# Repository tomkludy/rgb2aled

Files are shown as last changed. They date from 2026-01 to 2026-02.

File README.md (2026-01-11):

# rgb2aled

## What it does
This project allows you to connect 1 or 2 RGB LEDs to an addressable LED (WS2812) controller, and provides a standard WS2812 passthrough so that you can daisy-chain additional LEDs - or even daisy chain these controllers together. The LEDs must be 5V, common-anode.

Note that in its current form this cannot support 12V RGB LEDs nor common-cathode LEDs, though it shouldn't be super difficult to make variations to the design for those.

This device can be built for around $15 of materials, and the software is provided here free-of-charge.

## Why is it useful
I have been building a virtual pinball machine, following [Way of the Wrench](https://youtube.com/playlist?list=PLrqlHbqP7FINmGgJoszVvWOOyb8shdfUn&si=c6fxJmt26F5moLLm)'s build guide, but I am not using exactly the same parts. I have a [fire button lockdown bar](https://virtuapin.net/index.php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) from [Virtuapin.net](virtuapin.net), and I have 4 [RGB leaf buttons](https://www.clevelandsoftwaredesign.com/pinball-parts/p/rgb-true-leaf-button) from [Cleveland Software Design](clevelandsoftwaredesign.com). I was having trouble trying to connect them to my cabinet and control them with DOF since I don't have a 5V RGB LED controller. I foolishly tried connecting one to a 12V RGB controller and the "magic smoke" was released! (don't do that!) Emil's videos sparked the idea to adapt these LEDs to support the WS2812 addressable-LED standard, that way I can connect them to my Wemos lighting controller.

There are probably other use cases for hooking "regular" LEDs up to addressable-LED light strips. If you have another use case let me know!

## Hardware
To support 1 RGB LED, you'll need:
- 1x [Arduino Nano v3](https://a.co/d/9rjba7l). Any ATMega328P clone should work as long as it is running at 16MHz.
- 3x [resistors](https://a.co/d/9rjba7l) - anything from 1kΩ to 100kΩ should work fine. I used a mix of 10kΩ and 5.1kΩ resistors that I had lying around.
- 3x N-type MOSFETs. I used [IRLZ44Ns](https://a.co/d/9rjba7l).
- [Male and female JST 3-pin connectors](https://a.co/d/ethh2G7) to connect to a standard WS2812 daisy chain.
- 1x [RGB LED connector](https://a.co/d/aOVf79y).
- Something to mount it on. I used a [1/2 size breadboard from ElectroCookie](https://a.co/d/e8n7Chf).

If you want to support 2 RGB LEDs from one board, add to this:
- 3x additional resistors
- 3x additional N-type MOSFETs
- 1x additional RGB LED connector.

Sorry - there's no way to drive more than 2 LEDs from one Arduino Nano, at least not with this design. The Arduino only has 6 PWM output channels and each LED uses 3 of them. To support my 5 total RGB LEDs I just built 3 of these devices and daisy-chained them.

The board hooks up to a standard addressable-LED strip or controller, acts as 1 or 2 additional "pixels" driving 1 or two connected "dumb" LEDs, and then passes through up any remaining data to additional controllers or light strips.

> [!WARNING]
> Although any number of LEDs can be daisy chained from data-out, make sure if you have more than about 15 or so, that you inject power to the strip immediately after this board in the sequence. Each LED can use up to 60mA power at full brightness. A breadboard is usually only rated for 1-2 amps at most. Usually light strips have both an input connector and separate power and ground inputs - hook those directly to your 5V power supply to avoid sending that much current through this controller.

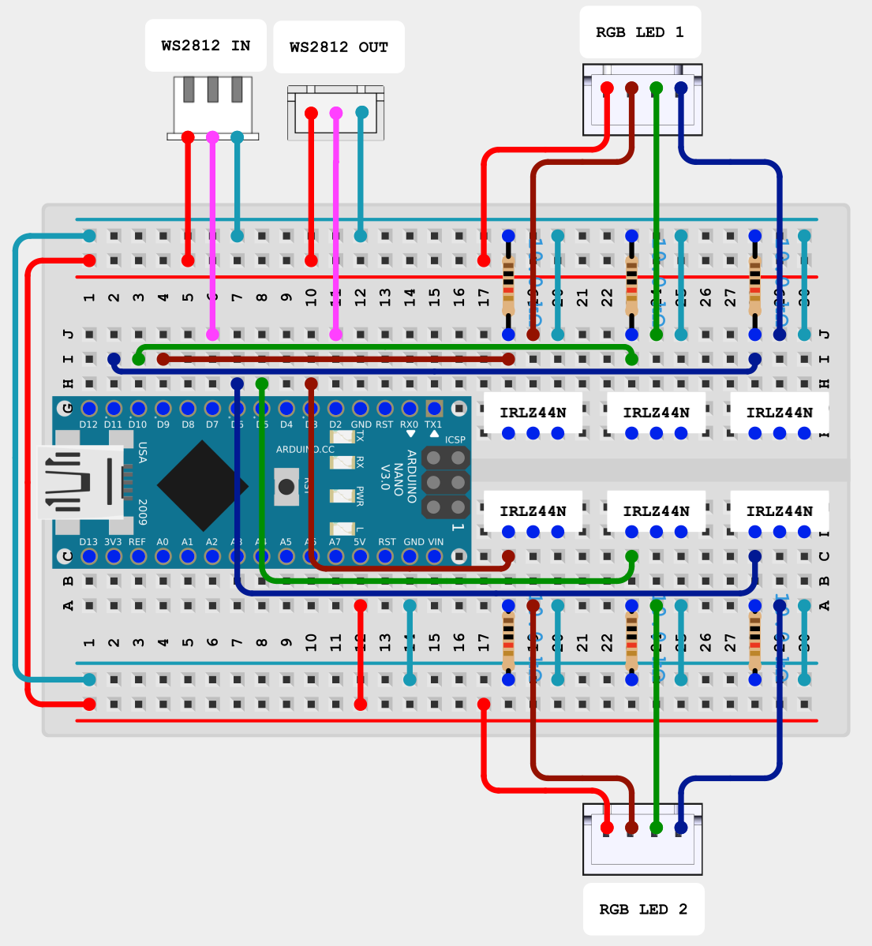
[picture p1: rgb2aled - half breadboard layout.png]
The schemetic diagram is shown [in the PDF](Schematic_RGB-to-ALED.pdf). This circuit will fit on a 1/2 size breadboard, though its a bit tight: 

## Software
Next you need to program the Arduino to make it function. Download and open the free Arduino IDE and create a "sketch". Insert the code from [the .ino file](rgb2aled.ino). If you have only one LED, comment out the line `#define TWO_LEDS`. **This is important!** The board will behave strangely if you don't set or unset `TWO_LEDS` correctly in the code, to match what you actually have connected to the device.

Compile and upload it to your Arduino. Note: I had to select "Tools > Processor > ATMega328P (Old Processor)" for my boards or the code would not upload; YMMV based on the exact hardware you have.

The 16MHz Arduino is just barely fast enough to handle the timing required by using hand-optimized assembly code with fully unrolled loops. As a result the code requires specific clock cycle timing and supports ONLY a 16MHz processor. There are 48MHz and faster Arduinos out there like the Nano r4 and the Nano 33, but those <ins>will not work</ins> with this software.

## Putting it all together
I created 3d-printable cases for these when they are built on the ElectroCookie 1/2-size breadboards; STLs are available in this repo. There are variations for 1 LED or 2 LEDs. Flip the top piece before printing to avoid using support.

To assemble, use M2 x 4mm screws to connect the breadboard to the bottom of the case, route the wires through the correct holes, then use M3 x 6mm screws to connect the top of the case to the bottom of the case. I also suggest a bit of glue gun where the wires pass through the case holes to hold them in place and prevent strain on the soldered wire connections.

## Contributing
If you want to help make this project better, feel free to contribute pull requests!

## FAQ

*Q: Will you sell me a pre-built version?*<br/>
A: No, building electronics is a hobby for me, not my day job. Perhaps someone else would be willing to build it in a more professional package (proper PCB for example) and sell it. You could probably get it made by PCBWay or another circuit manufacturer.

*Q: Can I build it and sell it myself?*<br/>
A: Everything in this repo is licensed under the Creative Commons Attribution License, meaning it is free to use, modify, and redistribute as long as you include attribution to the original author. So, yes! If you do build and sell it, let me know so that I can link to your product.

*Q: Will an Arduino Nano r4 or Nano 33 work?*<br/>
A: I presume the hardware could work if wired the same way, but the software would need to be completely rewritten since the timing is completely different for those boards.

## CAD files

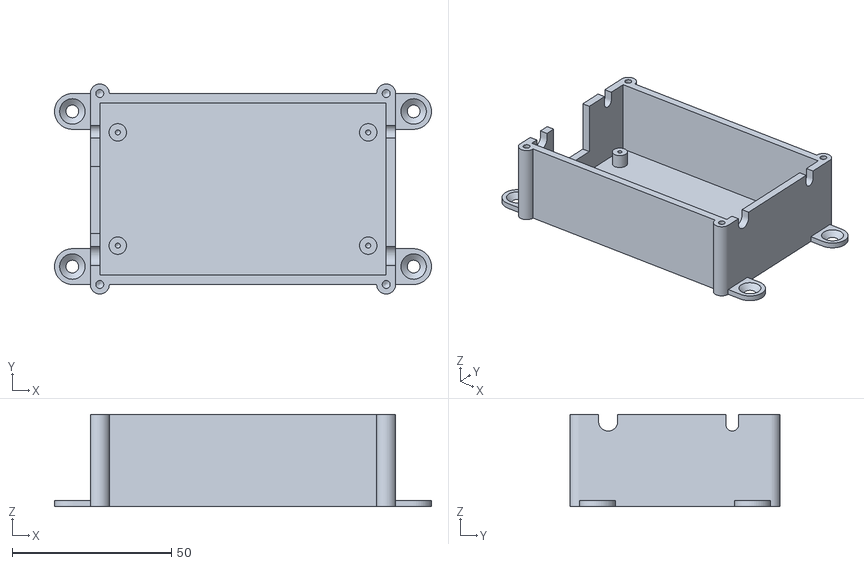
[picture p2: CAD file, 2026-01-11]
RGB to ARGB case - 2 LEDs - bottom.stl
118.5 x 66.0 x 29.0

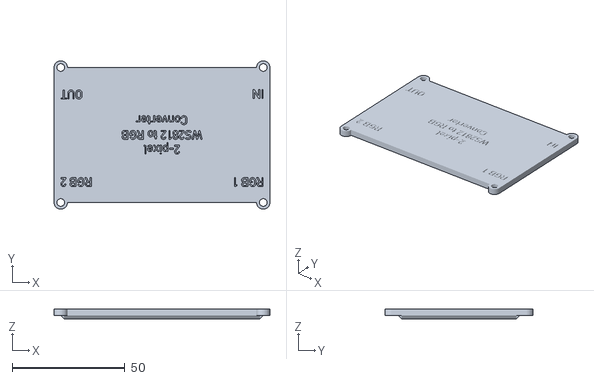
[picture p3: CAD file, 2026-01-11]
RGB to ARGB case - 2 LEDs - top.stl
96.0 x 66.0 x 4.50

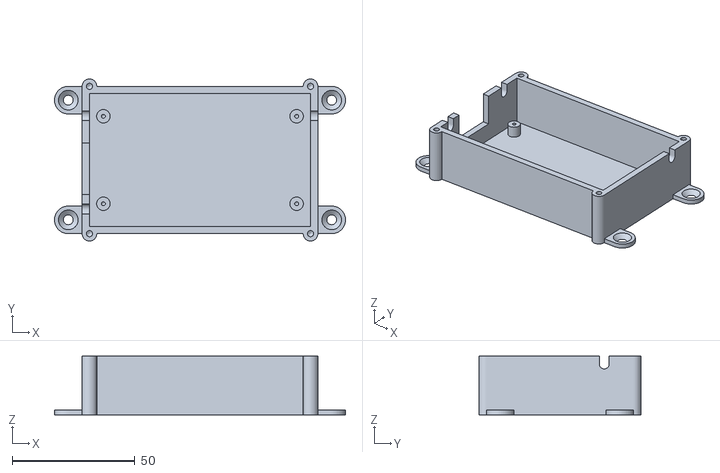
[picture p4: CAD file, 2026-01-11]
RGB to ARGB case - 1 LED - bottom.stl
118.5 x 66.0 x 24.0

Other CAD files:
RGB to ARGB case - 1 LED - top.stl

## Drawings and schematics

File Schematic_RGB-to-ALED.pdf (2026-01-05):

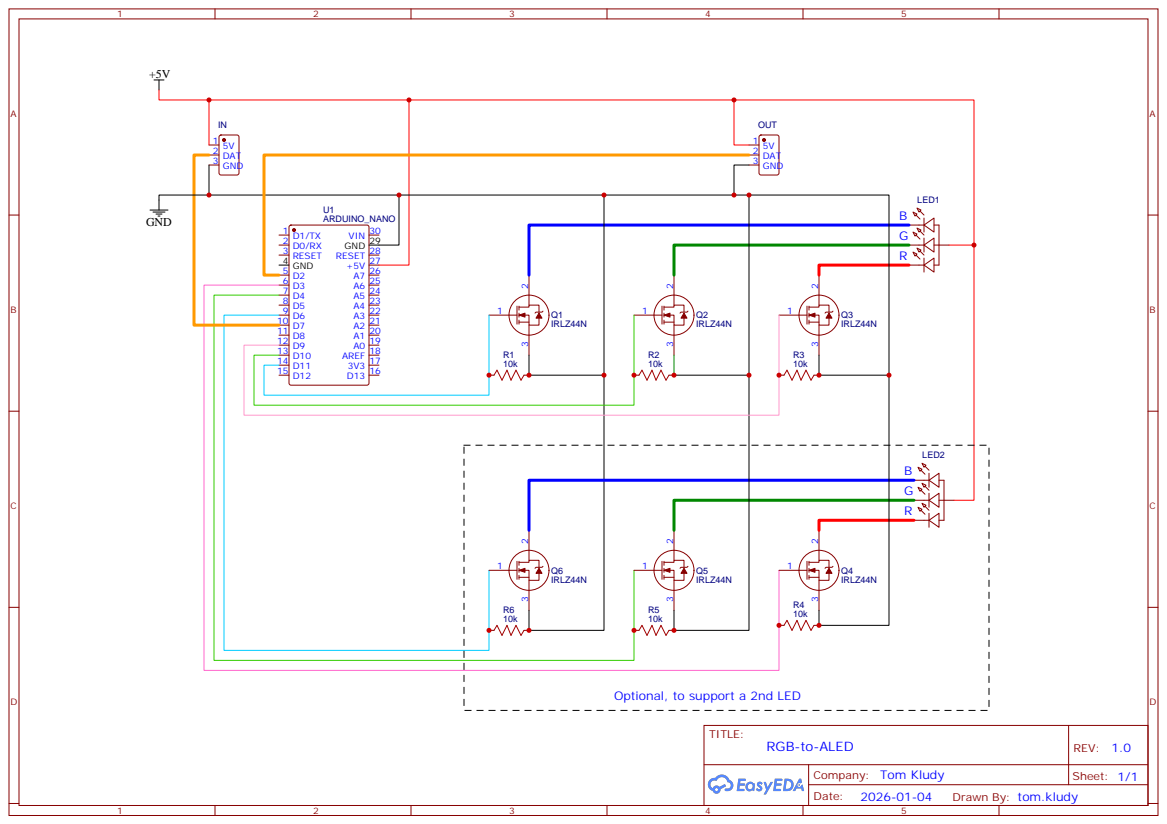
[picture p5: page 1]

Optional, to support a 2nd LED

Drawn By: tom.kludy

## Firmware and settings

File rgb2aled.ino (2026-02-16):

/**
 * WS2812B Hyper-Optimized 1/2 Pixel Controller
 * -------------------------------------------
 * - Target: ATmega328P @ 16MHz (1 cycle = 62.5ns)
 * - Sampling Window: 437.5ns - 562.5ns (Cycles 7-9)
 * - Relay: 1:1 pulse preservation with constant 6-cycle latency.
 * 
 * Captures two pixels (24 bits each, 48 bits total) from WS2812B data stream
 * and outputs the corresponding RGB values to two sets of 3 PWM pins each.
 * Then passes through all subsequent pixels in "burst relay mode".
 *
 * Components:
 * - Arduino Nano (ATmega328P @ 16MHz)
 * - 6x N-Channel Logic Level MOSFETs (e.g., IRLZ44N)
 * - 6x Resistors (10k Ohm) - 1k..100k acceptable
 * - 2x 5V Common-Anode RGB LEDs (LEDs to drive with this controller)
 *
 * Wiring expected:
 * - 5V -> Arduino 5V and LED Anodes
 * - GND -> Arduino GND and MOSFET Sources
 * - WS2812B Data In -> Arduino D7
 * - Arduino D2 -> WS2812B Data Out (daisy chain to rest of strip)
 * - Arduino D9 -> MOSFET 1 Gate -> 10k Resistor -> GND
 * - Arduino D10 -> MOSFET 2 Gate -> 10k Resistor -> GND
 * - Arduino D11 -> MOSFET 3 Gate -> 10k Resistor -> GND
 * - Arduino D3 -> MOSFET 4 Gate -> 10k Resistor -> GND (optional - for 2 LEDs)
 * - Arduino D5 -> MOSFET 5 Gate -> 10k Resistor -> GND (optional - for 2 LEDs)
 * - Arduino D6 -> MOSFET 6 Gate -> 10k Resistor -> GND (optional - for 2 LEDs)
 * - MOSFET 1 Drain: LED 1 RED Cathode
 * - MOSFET 2 Drain: LED 1 GREEN Cathode
 * - MOSFET 3 Drain: LED 1 BLUE Cathode
 * - MOSFET 4 Drain: LED 2 RED Cathode (optional - for 2 LEDs)
 * - MOSFET 5 Drain: LED 2 GREEN Cathode (optional - for 2 LEDs)
 * - MOSFET 6 Drain: LED 2 BLUE Cathode (optional - for 2 LEDs)
 *
 * Estimated max current draw, assuming 2 100mA RGB LEDs at full brightness and
 * no passthrough: 200mA (LEDs) + 30mA (Arduino Nano) = 230mA / 0.23A total, or
 * roughly 1.15W.
 *
 * Note that 5V and GND must be common through the full circuit, but if you are
 * building on a breadboard you should patch additional power into the strip
 * after this device and ensure you are using sufficient gauge wires. ALEDs are
 * typically rated for 60mA at full brightness. So to keep under 1A total, you
 * should not connect more than ~12 additional LEDs to the daisy chain output of
 * this controller without additional power injection.
 * 
 * 
 * rgb2aled  © 2026 by Tom Kludy is licensed under CC BY 4.0. To view a copy of
 * this license, visit https://creativecommons.org/licenses/by/4.0/
 */

#include <avr/io.h>

// Comment the following for 24-bit capture (1 LED).
#define TWO_LEDS

// There is a prototype variant of the board that uses D6 for data in and D7 for data out.
// I do not want to rewire it or maintain two separate codebases, so this define allows
// swapping the input and output pins as needed.
//#define ALTERNATE_DATA_PINS
#ifdef ALTERNATE_DATA_PINS
  #undef TWO_LEDS // ALTERNATE_DATA_PINS only supports 1 LED mode because D6 is used for data in.
  #define DATA_IN    6
  #define DATA_OUT   7
#else
  #define DATA_IN    7
  #define DATA_OUT   2
#endif

void setup() {
  noInterrupts();
  
  // Disable Arduino default timer interrupts
  TIMSK0 = 0; TIMSK1 = 0; TIMSK2 = 0;

  // Pin Direction Setup
  DDRB |= (1 << PB1) | (1 << PB2) | (1 << PB3);   // LED 1 (D9, D10, D11)
  DDRD |= (1 << DDD3) | (1 << DDD5) | (1 << DDD6); // LED 2 (D3, D5, D6)
  
  DDRD &= ~(1 << DATA_IN); // Input (Data In)
  DDRD |= (1 << DATA_OUT); // Output (Relayed Data Out)

  // PWM Timer Setup (Inverting Mode for Common Anode)
  TCCR0A = (1 << COM0A1) | (1 << COM0A0) | (1 << COM0B1) | (1 << COM0B0) | (1 << WGM01) | (1 << WGM00);
  TCCR0B = (1 << CS00);
  TCCR1A = (1 << COM1A1) | (1 << COM1A0) | (1 << COM1B1) | (1 << COM1B0) | (1 << WGM10);
  TCCR1B = (1 << WGM12) | (1 << CS10);
  TCCR2A = (1 << COM2A1) | (1 << COM2A0) | (1 << COM2B1) | (1 << COM2B0) | (1 << WGM21) | (1 << WGM20);
  TCCR2B = (1 << CS20);
  
  // Initialize LEDs to OFF (Common Anode 255 = Off)
  OCR0A = 255; OCR0B = 255; OCR1A = 255; OCR1B = 255; OCR2A = 255; OCR2B = 255;
}

void loop() {
  asm volatile(
    // --- MACROS ---

    // Reads 1 bit: Waits for Rise, Delays to Center, Samples, Waits for Fall
    //
    // Sampling window: 437.5ns - 562.5ns (Cycles 7-9)
    //
    // The Wemos S2 seems to have too short of a high bit pulse width, falling
    // around ~650ns instead of 800ns as expected by WS2812 spec. So we sample
    // earlier than the ideal center. This does run the risk that a LOW bit
    // could be misread as HIGH if the pulse drops late; by the spec, a LOW bit
    // can be as long as 500ns. However the Wemos S2 seems to have a maximum
    // LOW pulse width of around 400ns in practice.
    ".macro READ_BIT reg \n\t"
      // 1. Wait for Rise
      // Best Case (Rise just before sample): 2 cycles latency.
      // Worst Case (Rise just after sample): 4 cycles latency.
      "1: sbis 0x09, %[data_in] \n\t" "rjmp 1b \n\t"
      // [Range: T=2 to T=4] [125ns - 250ns]

      // 2. Delay to Center (4 NOPs + 1 LSL)
      "nop \n\t" "nop \n\t" "nop \n\t" "nop \n\t"
      "lsl \\reg \n\t"        
      // [Range: T=7 to T=9] [437.5ns - 562.5ns] 
      // *** SAMPLING POINT ***
      // WS2812B '0' is HIGH for ~300-400ns. WS2812B '1' is HIGH for ~625-800ns.

      // 3. Sample (2 cycles total)
      // Path 1 (Low): sbic(2) = 2.
      // Path 2 (High): sbic(1) + ori(1) = 2.
      "sbic 0x09, %[data_in] \n\t"     
      "ori \\reg, 1 \n\t"     
      // [Range: T=9 to T=11] [562.5ns - 687.5ns]

      // 4. Wait for Fall (Sync Anchor)
      // Best case (Already Low): sbic(2) = 2 cycles. [Exit T=11-13]
      // Worst case (Wait for edge): sbic(1)+rjmp(2)+sbic(2) = 5 cycles. [Exit T=14-16]
      "2: sbic 0x09, %[data_in] \n\t" "rjmp 2b \n\t"
    ".endm \n\t"

    ".macro READ_BYTE reg \n\t"
      "READ_BIT \\reg \n\t" "READ_BIT \\reg \n\t" "READ_BIT \\reg \n\t" "READ_BIT \\reg \n\t"
      "READ_BIT \\reg \n\t" "READ_BIT \\reg \n\t" "READ_BIT \\reg \n\t" "READ_BIT \\reg \n\t"
    ".endm \n\t"


    // --- 1. INITIAL POWER-ON SYNC ---
    "start_frame_%=: \n\t"
    #ifndef TWO_LEDS
      // since we aren't reading any values for LED 2, we initialize the
      // associated registers to OFF (255 due to inverted signal).
      "ldi r19, 255 \n\t" "ldi r20, 255 \n\t" "ldi r21, 255 \n\t"
    #endif
    "wait_reset_%=: \n\t"
      "ldi r22, 250 \n\t"
    "r_chk_%=: \n\t"
      "sbic 0x09, %[data_in] \n\t" "jmp wait_reset_%= \n\t" 
      "dec r22 \n\t" "brne r_chk_%= \n\t"


    // --- 2. CAPTURE PHASE ---
    "capture_start_%=: \n\t"
    "READ_BYTE r16 \n\t" // G1
    "READ_BYTE r17 \n\t" // R1
    "READ_BYTE r18 \n\t" // B1

    #ifdef TWO_LEDS
      "READ_BYTE r19 \n\t" // G2
      "READ_BYTE r20 \n\t" // R2
      "READ_BYTE r21 \n\t" // B2
    #endif


    // --- 3. RELAY PHASE ---
    "relay_entry_%=: \n\t"
      // Linear timeout: 256 checks * 3 cycles + 4 cycles = 772 cycles (~48us reset window)
      // When LOW: 3 cycles per check (sbis + rjmp)
      // When HIGH occurs at the moment of sbis: 0 cycle delay
      // When HIGH occurs just after sbis: 2 cycles delay (rjmp)
      // Thus, we can be between 0-2 cycles late when detecting HIGH.
      ".rept 256 \n\t"
        "sbis 0x09, %[data_in] \n\t"  // Cycles 1-2: If HIGH, skip next (if LOW, only 1 cycle)
        "rjmp .+6 \n\t"               // Cycles 2-3: If LOW, skip to next iteration

        // The rjmp offset doesn't support labels because we are in a .rept loop.
        // So we need to manually calculate the offset to jump. Each of the
        // instructions is labeled with instruction byte counts for clarity;
        // eg. "[2]" means 2 bytes for instruction(s) on that line. You can
        // then sum those up and make sure the rjmp offset above is correct.

        // We need to keep the bit-start latency to a minimum so we can't spend any
        // extra cycles jumping out of the loop. But we also need to keep the number
        // of instructions in the loop down to avoid "relocation truncated to fit"
        // compilation error.
        "sbi 0x0b, %[data_out] \n\t"  // [2] Cycles 3-4: set HIGH (Pin High at the end of cycle 4)
        "jmp relay_bit_%= \n\t"       // [4] Cycles 5-7: get out of the .rept
      ".endr \n\t"
      "jmp update_now_%= \n\t"        // If we finish 256 reps, it's a RESET. Update LEDs.

    "relay_bit_%=: \n\t"

      // set LOW if 0, clock-synced:  // LOW path  / HIGH path
      "sbis 0x09, %[data_in] \n\t"    // 8         / 8-9   : Sample D7
      "cbi 0x0b, %[data_out] \n\t"    // 9-10      / -     : Set D2 to match D7; 0-bit HIGH duration=6 cycles
      "sbic 0x09, %[data_in] \n\t"    // 11-12     / 10    : Skip next if D7 HIGH
      "rjmp .+0 \n\t"                 // -         / 11-12 : Sync cycle count

      "nop \n\t"                      // Cycle 13

      "cbi 0x0b, %[data_out] \n\t"    // Cycles 14-15: set output LOW (at end of cycle 15); 1-bit HIGH duration=11 cycles
      "jmp relay_entry_%= \n\t"       // Cycles 16-18: Loop back to check for next bit


    // --- 4. UPDATE PHASE ---
    // The only way that we get here is by jumping through 256 relay checks above
    // without seeing any HIGH on the input line. This indicates a reset period.
    //
    // This code executes during the reset gap, when we have a lot of extra time before
    // we expect the next frame to start. (Reset is usually >300ns.) We use this time to do all of the work
    // that we deferred during the capture and relay phases.
    "update_now_%=: \n\t"

    // Invert captured values for Common Anode LEDs
    "com r16 \n\t" "com r17 \n\t" "com r18 \n\t"
    #ifdef TWO_LEDS
      // we only want to invert these if we read them from input;
      // when !TWO_LEDS, we want to leave these untouched so they
      // always contain the OFF value.
      "com r19 \n\t" "com r20 \n\t" "com r21 \n\t"
    #endif

    // Commit to PWM registers
    "sts 0x88, r17 \n\t" // OCR1A (D9)  - LED1 Red
    "sts 0x8A, r16 \n\t" // OCR1B (D10) - LED1 Green
    "sts 0xB3, r18 \n\t" // OCR2A (D11) - LED1 Blue

    "sts 0xB4, r20 \n\t" // OCR2B (D3)  - LED2 Red
    "sts 0x48, r19 \n\t" // OCR0B (D5)  - LED2 Green
    "sts 0x47, r21 \n\t" // OCR0A (D6)  - LED2 Blue

    // Jump directly to capture bits for the next frame.
    "jmp capture_start_%= \n\t" 

    :
    : [data_in] "I" (DATA_IN), [data_out] "I" (DATA_OUT)
    : "r16", "r17", "r18", "r19", "r20", "r21", "r22", "r23", "memory"
  );
}

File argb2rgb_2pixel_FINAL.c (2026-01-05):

/**
 * WS2812B two-pixel ARGB to RGB controller
 *
 * Captures two pixels (24 bits each, 48 bits total) from WS2812B data stream
 * and outputs the corresponding RGB values to two sets of 3 PWM pins each.
 * Then passes through all subsequent pixels in "burst mode", up to 200 pixels
 * total.
 *
 * The timing is carefully tuned for an Arduino Nano (ATmega328P @ 16MHz).
 * It cannot support more than 200 pixels due to timing constraints; even
 * switching the timer counter to 16 bits from 8 bits causes timing issues.
 * This is the primary limiting factor for longer strips.
 *
 * Components:
 * - Arduino Nano (ATmega328P @ 16MHz)
 * - 6x N-Channel Logic Level MOSFETs (e.g., IRLZ44N)
 * - 6x Resistors (10k Ohm) - 1k..100k acceptable
 * - 2x 5V Common-Anode RGB LEDs (LEDs to drive with this controller)
 *
 * Wiring expected:
 * - 5V -> Arduino 5V and LED Anodes
 * - GND -> Arduino GND and MOSFET Sources
 * - WS2812B Data In -> Arduino D7
 * - Arduino D2 -> WS2812B Data Out (daisy chain to rest of strip)
 * - Arduino D9 -> MOSFET 1 Gate -> 10k Resistor -> GND
 * - Arduino D10 -> MOSFET 2 Gate -> 10k Resistor -> GND
 * - Arduino D11 -> MOSFET 3 Gate -> 10k Resistor -> GND
 * - Arduino D3 -> MOSFET 4 Gate -> 10k Resistor -> GND
 * - Arduino D5 -> MOSFET 5 Gate -> 10k Resistor -> GND
 * - Arduino D6 -> MOSFET 6 Gate -> 10k Resistor -> GND
 * - MOSFET 1 Drain: LED 1 RED Cathode
 * - MOSFET 2 Drain: LED 1 GREEN Cathode
 * - MOSFET 3 Drain: LED 1 BLUE Cathode
 * - MOSFET 4 Drain: LED 2 RED Cathode
 * - MOSFET 5 Drain: LED 2 GREEN Cathode
 * - MOSFET 6 Drain: LED 2 BLUE Cathode
 *
 * Note that 5V and GND must be common through the full circuit, but if you are
 * building on a breadboard you should connect the 5V wires directly from the
 * input to the output connector (or patch additional power into the strip
 * after this device) and ensure you are using sufficient gauge wires.
 * **Breadboard rails are only rated for 1A.**
 *
 * Estimated max current draw, assuming 2 100mA RGB LEDs at full brightness and
 * no passthrough: 200mA (LEDs) + 30mA (Arduino Nano) = 230mA / 0.23A total, or
 * roughly 1.15W.
 *
 * Estimated max current draw, assuming 2 100mA RGB LEDs plus 200 passthrough
 * WS2812B LEDs (60mA each) at full brightness: 200mA (LEDs) + 30mA (Arduino
 * Nano) + 12,000mA (passthrough) = 12,230mA / 12.23A total, or roughly 61.15W.
 */

#include <avr/io.h>

// --- CONFIGURATION FLAG ---
// Uncomment for 2 LEDs (48-bit capture). 
// Comment out for 1 LED (24-bit capture + early pass-through).
#define TWO_LEDS

void setup() {
  // --- HARDWARE LOCK ---
  noInterrupts();
  TIMSK0 = 0; // Explicitly kill Timer 0 interrupts (millis/delay)
  TIMSK1 = 0;
  TIMSK2 = 0;

  // LED 1 Pins: D9, D10, D11 (Port B1, B2, B3)
  // LED 2 Pins: D3, D5, D6 (Port D3, D5, D6)
  DDRB |= (1 << PB1) | (1 << PB2) | (1 << PB3);
  DDRD |= (1 << DDD3) | (1 << DDD5) | (1 << DDD6);
  
  // Data Pins: D7 In, D2 Out
  DDRD &= ~(1 << DDD7);
  DDRD |= (1 << DDD2);

  // --- PWM SETUP (INVERTING MODE) ---
  TCCR0A = (1 << COM0A1) | (1 << COM0A0) | (1 << COM0B1) | (1 << COM0B0) | (1 << WGM01) | (1 << WGM00);
  TCCR0B = (1 << CS00);
  TCCR1A = (1 << COM1A1) | (1 << COM1A0) | (1 << COM1B1) | (1 << COM1B0) | (1 << WGM10);
  TCCR1B = (1 << WGM12) | (1 << CS10);
  TCCR2A = (1 << COM2A1) | (1 << COM2A0) | (1 << COM2B1) | (1 << COM2B0) | (1 << WGM21) | (1 << WGM20);
  TCCR2B = (1 << CS20);

  // Default OFF
  OCR0A = 255; OCR0B = 255; 
  OCR1A = 255; OCR1B = 255;
  OCR2A = 255; OCR2B = 255;
}

void loop() {
  asm volatile(
    "start_frame_%=: \n\t"
    
    "wait_reset_%=: \n\t"
      "ldi r22, 250 \n\t"
    "r_chk_%=: \n\t"
      "sbic 0x09, 7 \n\t" "jmp wait_reset_%= \n\t" 
      "dec r22 \n\t" "brne r_chk_%= \n\t"

    // --- CAPTURE MACRO (Tuned for 16MHz) ---
    ".macro CAPT_SHIELD reg \n\t"
      "ldi r24, 8 \n\t"
    "10: sbis 0x09, 7 \n\t" "rjmp 10b \n\t"      
      "nop \n\t" "nop \n\t" "nop \n\t" "nop \n\t" // 4 NOPs for center-sampling
      "in r25, 0x09 \n\t" "lsl \\reg \n\t" 
      "sbrc r25, 7 \n\t" "ori \\reg, 1 \n\t"     
    "11: sbic 0x09, 7 \n\t" "rjmp 11b \n\t"      
      "dec r24 \n\t" "brne 10b \n\t"
      "com \\reg \n\t" 
    ".endm \n\t"

    "CAPT_SHIELD r16 \n\t" "CAPT_SHIELD r17 \n\t" "CAPT_SHIELD r18 \n\t" // Pixel 1

    #ifdef TWO_LEDS
      "CAPT_SHIELD r19 \n\t" "CAPT_SHIELD r20 \n\t" "CAPT_SHIELD r21 \n\t" // Pixel 2
    #else
      // Skip capture, keep LED2 pins off (255 = 0% duty in inverting mode)
      "ldi r19, 255 \n\t" "ldi r20, 255 \n\t" "ldi r21, 255 \n\t"
    #endif

    // --- RELAY MACRO ---
    "ldi r22, 200 \n\t"
    "px_loop_%=: \n\t"
      ".macro SMASH_SHIELD \n\t"
        "30: sbis 0x09, 7 \n\t" "rjmp 30b \n\t"    
          "sbi 0x0b, 2 \n\t" "nop \n\t" 
          "sbis 0x09, 7 \n\t" "cbi 0x0b, 2 \n\t"   
        "31: sbic 0x09, 7 \n\t" "rjmp 31b \n\t"    
          "cbi 0x0b, 2 \n\t"                      
      ".endm \n\t"
      "SMASH_SHIELD \n\t" "SMASH_SHIELD \n\t" "SMASH_SHIELD \n\t" "SMASH_SHIELD \n\t"
      "SMASH_SHIELD \n\t" "SMASH_SHIELD \n\t" "SMASH_SHIELD \n\t" "SMASH_SHIELD \n\t"
      "SMASH_SHIELD \n\t" "SMASH_SHIELD \n\t" "SMASH_SHIELD \n\t" "SMASH_SHIELD \n\t"
      "SMASH_SHIELD \n\t" "SMASH_SHIELD \n\t" "SMASH_SHIELD \n\t" "SMASH_SHIELD \n\t"
      "SMASH_SHIELD \n\t" "SMASH_SHIELD \n\t" "SMASH_SHIELD \n\t" "SMASH_SHIELD \n\t"
      "SMASH_SHIELD \n\t" "SMASH_SHIELD \n\t" "SMASH_SHIELD \n\t" "SMASH_SHIELD \n\t"
      "dec r22 \n\t" 
      "breq update_now_%= \n\t"
      "jmp px_loop_%= \n\t" 
    "update_now_%=: \n\t"

    // --- COMMIT ---
    "sts 0x88, r17 \n\t" // LED1 RED
    "sts 0x8A, r16 \n\t" // LED1 GREEN
    "sts 0xB3, r18 \n\t" // LED1 BLUE
    "sts 0xB4, r20 \n\t" // LED2 RED
    "sts 0x48, r19 \n\t" // LED2 GREEN
    "sts 0x47, r21 \n\t" // LED2 BLUE

    "jmp start_frame_%= \n\t"

    : : : "r16", "r17", "r18", "r19", "r20", "r21", "r22", "r24", "r25", "memory"
  );
}

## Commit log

2026-01-05 Refactor pixel capture and relay assembly macros
    Updated the assembly macros for pixel capture and relay modes, ensuring proper timing and handling for both one and two LED configurations.
2026-01-10 Enhance README with detailed project info
    Expanded project description and hardware requirements, clarified LED compatibility, and updated software instructions.
2026-01-11 Revise wiring instructions and add PNG reference
    Updated wiring instructions and added a note about the PNG layout.
2026-01-11 Revise wiring section in README.md
    Updated the wiring diagram reference and added an image for layout.
2026-01-11 Rename ARGB2RGB1 case v4-bottom.stl to RGB to ARGB case - 1 LED - bottom.stl
    [RGB to ARGB case - 1 LED - bottom.stl]
2026-01-11 Rename ARGB2RGB1 case v6 - top.stl to RGB to ARGB case - 1 LED - top.stl
    [RGB to ARGB case - 1 LED - top.stl]
2026-01-11 Rename ARGB2RGB2 case v1 - bottom.stl to RGB to ARGB2 case - 2 LEDs - bottom.stl
    [RGB to ARGB2 case - 2 LEDs - bottom.stl]
2026-01-11 Rename ARGB2RGB2 case v3 - top.stl to RGB to ARGB case - 2 LEDs - top.stl
    [RGB to ARGB case - 2 LEDs - top.stl]
2026-01-11 Rename RGB to ARGB2 case - 2 LEDs - bottom.stl to RGB to ARGB case - 2 LEDs - bottom.stl
    [RGB to ARGB case - 2 LEDs - bottom.stl]
2026-01-11 Revise README with updated case assembly instructions
    Updated assembly instructions for 3D-printable cases, including variations for LED configurations and printing tips.
